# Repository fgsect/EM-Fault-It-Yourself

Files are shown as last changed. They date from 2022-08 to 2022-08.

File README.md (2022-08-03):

# EM-Fault It Yourself
This repository contains supplementary hardware design files and software to our paper 
[*EM-Fault It Yourself: Building a Replicable EMFI Setup for Desktop and Server Hardware*](). 
You can view it as a starting point to build your own customizable and open-source electromagnetic fault injection 
setup.

- `emfi_station/` contains the main controller software
- `marlin/` contains [Marlin](https://marlinfw.org/) configuration files
- `hardware/` contains hardware design files for 3D-printable parts

Detailed information can be found in the `README.md` files of the subdirectories.

## Software
The main controller software is a Python package called `emfi_station`. It provides a web interface to control the XYZ
stage, watch camera and sensor data and orchestrate complete electromagnetic fault injection attacks. To install the 
package clone this repository and run `pip`:

```shell
git clone 
pip install .
```

You can run *EMFI Station* using the command line:

```shell
usage: emfi-station [-h] [-i HOST] [-p PORT] [-s] [-a ATTACK_DIR] [-l LOG_DIR] [--marlin MARLIN] [--cal_cam CAL_CAM] [--pos_cam POS_CAM] [-v]

EMFI Station - Orchestrate electromagnetic fault injection attacks

options:
  -h, --help            show this help message and exit
  -i HOST, --host HOST  hostname or ip address
  -p PORT, --port PORT  http port (websocket port = http port + 1)
  -s, --simulate        simulate connection to Marlin
  -a ATTACK_DIR, --attack_dir ATTACK_DIR
                        attack scripts directory
  -l LOG_DIR, --log_dir LOG_DIR
                        log files directory
  --marlin MARLIN       (vendor_id, product_id) of Marlin board
  --cal_cam CAL_CAM     (vendor_id, product_id) of calibration camera
  --pos_cam POS_CAM     (vendor_id, product_id) of positioning camera
  -v, --verbosity       enable info log level
```

### Attack Scripts
The *EMFI Station* has an interface in the form of an `Attack` base class (`attack.py`) to allow easy integration of 
task/attack scripts. Your own task/attack class should inherit from the base class and implement the required 
methods. Each class should have its own file and a unique name (name() method). You can specify a folder containing 
attack scripts in the command line parameters.

## Troubleshooting
If you experience a `select timeout` while running *EMFI Station* under Raspbian, please try to adjust the quirks 
parameter of the `uvcvideo` kernel module:

```shell
rmmod uvcvideo
modprobe uvcvideo quirks=0x80
```

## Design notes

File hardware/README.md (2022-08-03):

# Hardware
The *EMFI Station* hardware is built out of commercially available as well as 3D-printable parts. Aluminum construction
profiles are used as a base frame for the other components:

<p align="center">
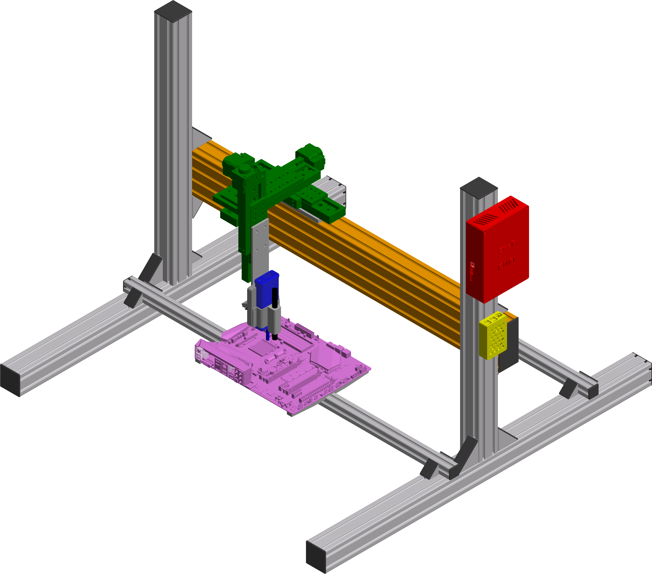
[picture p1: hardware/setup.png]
    
</p>

The following parts are commercially available:

- 1x [ChipShouter](https://www.newae.com/products/NAE-CW520)
- 3x [Standa 8MT175-100](https://www.standa.lt/products/catalog/motorised_positioners?item=60&prod=motorized_linear_stages)
- 3x [TMC2209 Stepper Driver](https://biqu.equipment/collections/driver-board/products/bigtreetech-tmc2209-stepper-motor-driver-for-3d-printer-board-vs-tmc2208)
- 1x [Bigtreetech SKR Pro v1.2](https://biqu.equipment/collections/control-board/products/bigtreetech-skr-pro-v1-1-32-bit-control-board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)
- 1x [Raspberry Pi 3B+](https://www.raspberrypi.com/products/raspberry-pi-3-model-b-plus/)
- 1x [Adafruit MLX90640 Thermal Camera](https://www.adafruit.com/product/4469)
- 1x [USB Microscope B007](https://www.supereyes-store.com/collections/microscopes/products/b007-300x-handheld-usb-digital-microscope-loupe-otoscope-magnifier-with-led-metal-stand)
- 1x [USB Microscope](https://www.amazon.de/TOOLCRAFT-Mikroskop-Pixel-Digitale-Vergr%C3%B6%C3%9Ferung/dp/B07L8M5BDJ)
- 1x [Power Supply](http://www.leicke.eu/de/products/NT03244)
- 1x [Angle Bracket](https://www.edmundoptics.de/p/metric-type-small-size-right-angle-bracket/12228/)
- 1x Aluminum Adapter Plates

All parts are mounted on an aluminum frame consisting of aluminum construction profiles. Please select these based on 
your needs. We used the following parts to achieve a working area large enough to target desktop and server hardware:

- 1x [12x6x100cm Profile](https://www.item24.com/en-de/profile-6-120x60-light-natural-41910/)
- 2x [6x6x100cm Profile](https://www.item24.com/en-de/profile-6-60x60-light-natural-41909/)
- 2x [3x3x100cm Profile](https://www.item24.com/en-de/profile-6-30x30-light-natural-41906/)
- 2x [6x6x70cm Profile](https://www.item24.com/en-de/profile-6-60x60-light-natural-41909/)
- 8x [6x6cm Angle](https://www.item24.com/en-de/angle-bracket-set-6-60x60-41968/)
- 8x [3x3cm Angle](https://www.item24.com/en-de/angle-bracket-set-6-30x30-41967/)
- Some [T-slot nuts](https://www.item24.com/en-de/t-slot-nut-f-6-st-m4-bright-zinc-plated-61323/)
- Some screws

Next to the commercially available parts, we 3D-printed mounts, cases and adapters. To allow an easy assembly, 
[threaded inserts](https://www.ruthex.de/collections/gewindeeinsatze) were used whenever threads were necessary in a 
3D-printed part. This folder contains all design (Autodesk Inventor (\*.ipt)) and print files (*.stl, *.stp):

- `skr_pro_case/` - Bigtreetech SKR Pro Case
- `ir_camera_mount/` - Thermal Camera Mount
- `chipshouter_mount/` - ChipShouter and Microscope Mount
- `atx_mount/` - ATX Mainboard Mount

Two aluminum adapter plates were specially produced based on our design. You can find the adapter plate design files 
in `adapter_plates/`.

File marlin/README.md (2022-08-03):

# Marlin Configuration
The XYZ stages are controlled by a 
[Bigtreetech SKR Pro v1.2](https://biqu.equipment/collections/control-board/products/bigtreetech-skr-pro-v1-1-32-bit-control-board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)
3D-printer mainboard running [Marlin](). It is equipped with 
[TMC2209 stepper drivers](https://biqu.equipment/collections/driver-board/products/bigtreetech-tmc2209-stepper-motor-driver-for-3d-printer-board-vs-tmc2208)
for quiet and smooth movements.

You can use the provided configuration files to build a custom firmware version based on **Marlin 2.0.9.2**. We 
configured Marlin to work best with the stepper drivers and *EMFI Station*. More information on how to build and 
configure the firmware can be found in the [Marlin installation guide](https://marlinfw.org/docs/basics/install.html).

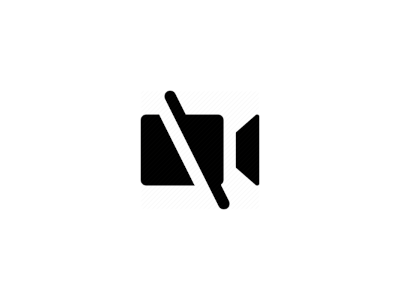
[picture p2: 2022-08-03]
emfi_station/web/cam_unavailable.png

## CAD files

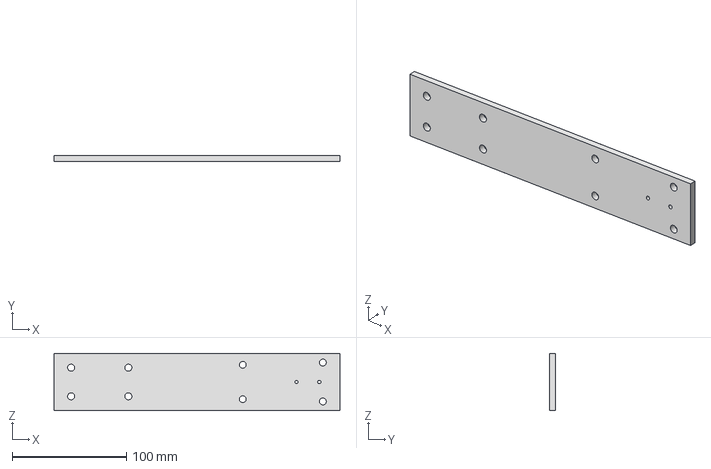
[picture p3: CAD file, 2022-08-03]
hardware/adapter_plates/adapter_chipshouter.stp
250.0 x 5.00 x 50.0 mm

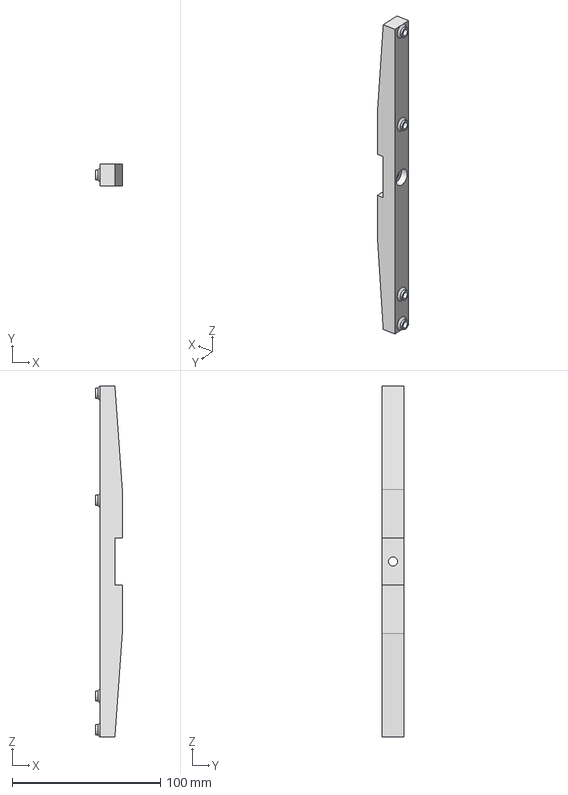
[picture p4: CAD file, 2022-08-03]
hardware/atx_mount/atx_mount.stp
18.0 x 15.0 x 237.0 mm

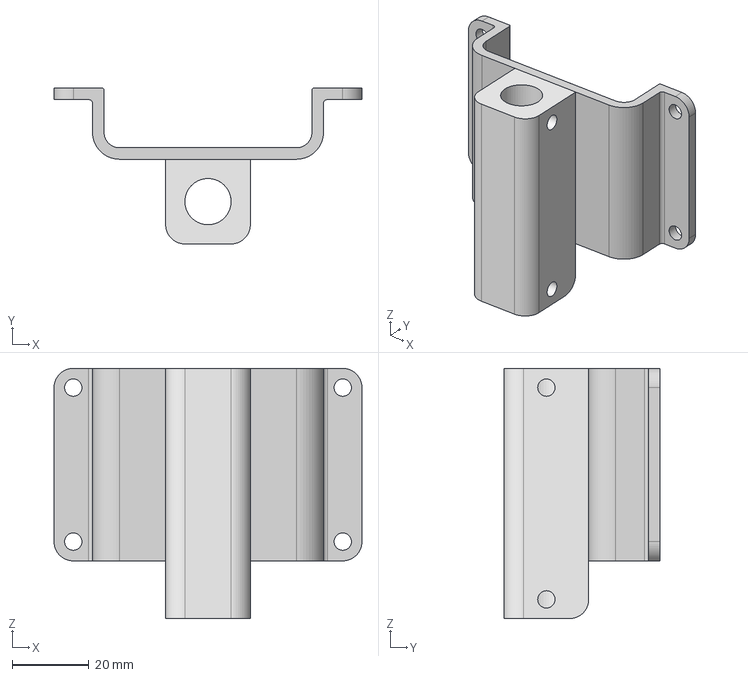
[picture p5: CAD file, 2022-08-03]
hardware/chipshouter_mount/chipshouter_mount.stp
80.0 x 40.5 x 65.0 mm
microscope_mount
chipshouter_mount_bracket

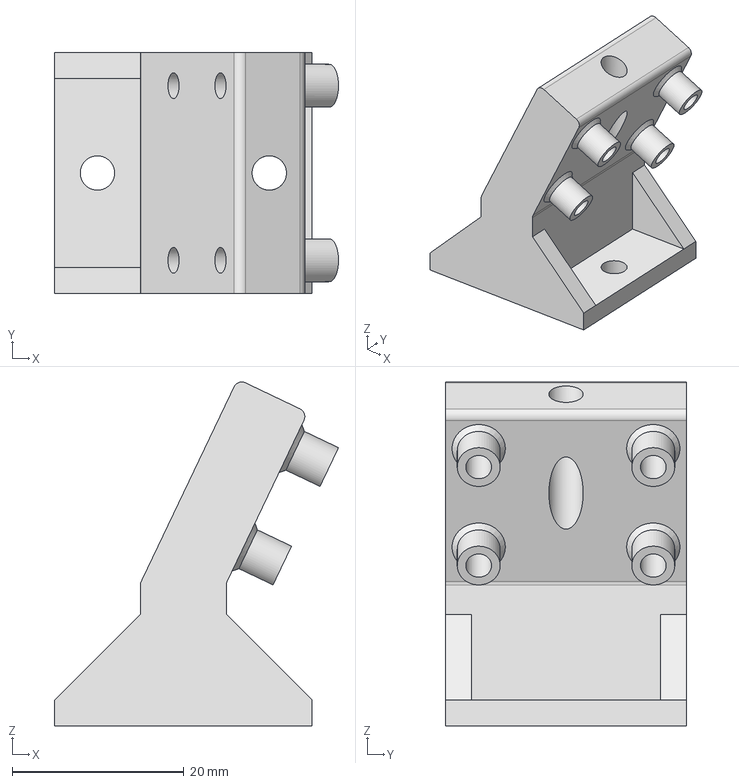
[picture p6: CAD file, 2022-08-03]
hardware/ir_camera_mount/ir_camera_mount.stp
33.1 x 28.0 x 40.0 mm

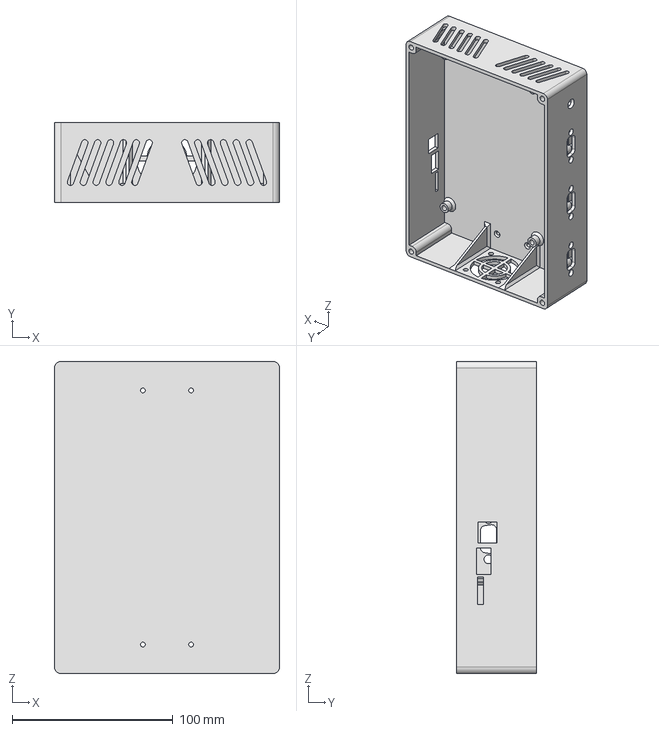
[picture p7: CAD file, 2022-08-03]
hardware/skr_pro_case/skr_case.stp
140.0 x 50.0 x 194.0 mm

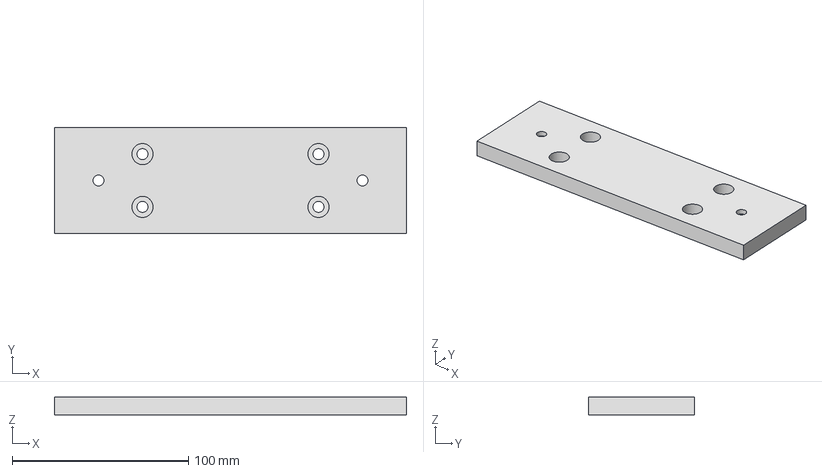
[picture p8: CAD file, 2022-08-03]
hardware/adapter_plates/adapter_stage.stp
200.0 x 60.0 x 10.0 mm

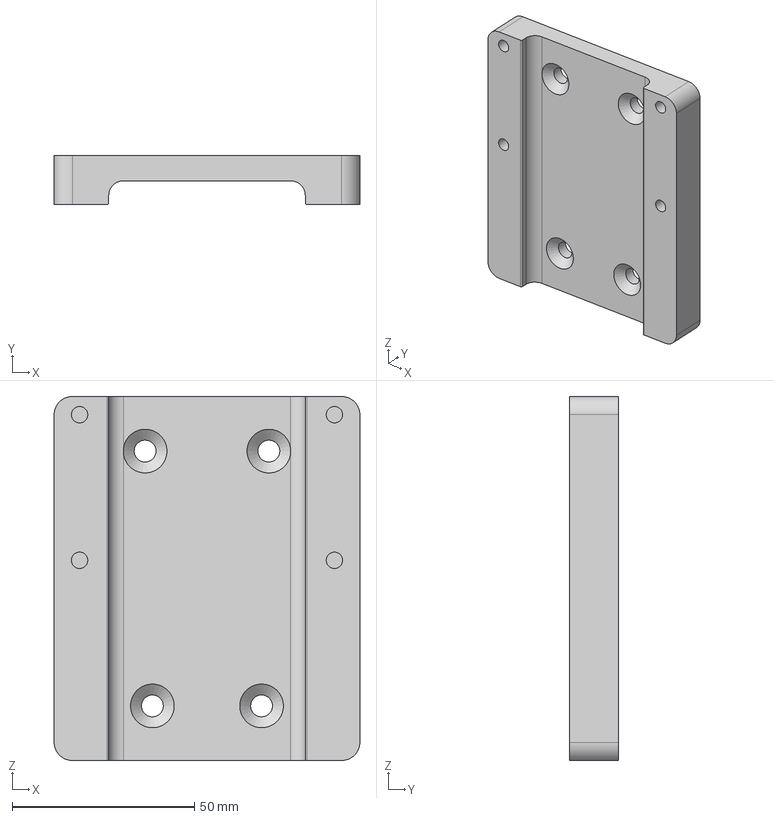
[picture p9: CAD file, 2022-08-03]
hardware/chipshouter_mount/chipshouter_mount_bottom.stp
84.0 x 13.5 x 100.0 mm

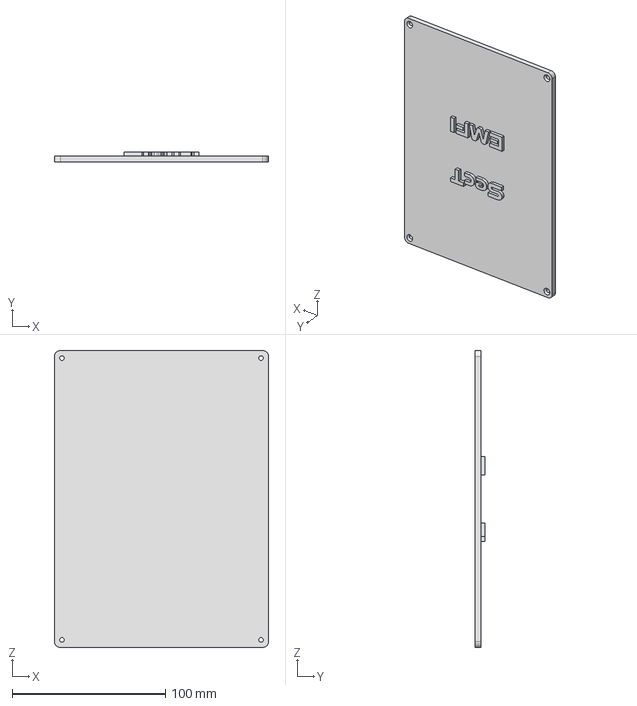
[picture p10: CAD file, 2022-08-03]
hardware/skr_pro_case/skr_case_top.stp
140.0 x 6.50 x 194.0 mm

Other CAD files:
hardware/adapter_plates/adapter_chipshouter.ipt
hardware/adapter_plates/adapter_chipshouter.stl
hardware/adapter_plates/adapter_stage.ipt
hardware/adapter_plates/adapter_stage.stl
hardware/atx_mount/atx_mount.ipt
hardware/atx_mount/atx_mount.stl
hardware/chipshouter_mount/chipshouter_mount.stl
hardware/chipshouter_mount/chipshouter_mount_assembly.iam
hardware/chipshouter_mount/chipshouter_mount_bottom.ipt
hardware/chipshouter_mount/chipshouter_mount_bottom.stl
hardware/chipshouter_mount/chipshouter_mount_bracket.ipt
hardware/chipshouter_mount/microscope_mount.ipt
hardware/ir_camera_mount/ir_camera_mount.ipt
hardware/ir_camera_mount/ir_camera_mount.stl
hardware/skr_pro_case/skr_case.ipt
hardware/skr_pro_case/skr_case.stl
hardware/skr_pro_case/skr_case_top.ipt
hardware/skr_pro_case/skr_case_top.stl

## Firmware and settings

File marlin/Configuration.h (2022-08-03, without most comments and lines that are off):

#pragma once
#define CONFIGURATION_H_VERSION 02000902
#define STRING_CONFIG_H_AUTHOR "(niclasku)" // Who made the changes.
#define SHOW_BOOTSCREEN
#define SERIAL_PORT -1
#define BAUDRATE 250000
  #define MOTHERBOARD BOARD_BTT_SKR_PRO_V1_2
#define CUSTOM_MACHINE_NAME "XYZ Controller"
#define MACHINE_UUID "5f4cca6f-12ec-4dfb-b79a-414b8f90fdfe"
#define LINEAR_AXES 3
#if LINEAR_AXES >= 4
  #define AXIS4_NAME 'A' // :['A', 'B', 'C', 'U', 'V', 'W']
#endif
#if LINEAR_AXES >= 5
  #define AXIS5_NAME 'B' // :['A', 'B', 'C', 'U', 'V', 'W']
#endif
#if LINEAR_AXES >= 6
  #define AXIS6_NAME 'C' // :['A', 'B', 'C', 'U', 'V', 'W']
#endif
#define EXTRUDERS 0
#define DEFAULT_NOMINAL_FILAMENT_DIA 1.75
#define TEMP_SENSOR_0 0
#define TEMP_SENSOR_1 0
#define TEMP_SENSOR_2 0
#define TEMP_SENSOR_3 0
#define TEMP_SENSOR_4 0
#define TEMP_SENSOR_5 0
#define TEMP_SENSOR_6 0
#define TEMP_SENSOR_7 0
#define TEMP_SENSOR_BED 0
#define TEMP_SENSOR_PROBE 0
#define TEMP_SENSOR_CHAMBER 0
#define TEMP_SENSOR_COOLER 0
#define TEMP_SENSOR_BOARD 0
#define TEMP_SENSOR_REDUNDANT 0
#define DUMMY_THERMISTOR_998_VALUE  25
#define DUMMY_THERMISTOR_999_VALUE 100
#define TEMP_RESIDENCY_TIME         10  // (seconds) Time to wait for hotend to "settle" in M109
#define TEMP_WINDOW                  1  // (°C) Temperature proximity for the "temperature reached" timer
#define TEMP_HYSTERESIS              3  // (°C) Temperature proximity considered "close enough" to the target
#define TEMP_BED_RESIDENCY_TIME     10  // (seconds) Time to wait for bed to "settle" in M190
#define TEMP_BED_WINDOW              1  // (°C) Temperature proximity for the "temperature reached" timer
#define TEMP_BED_HYSTERESIS          3  // (°C) Temperature proximity considered "close enough" to the target
#define TEMP_CHAMBER_RESIDENCY_TIME 10  // (seconds) Time to wait for chamber to "settle" in M191
#define TEMP_CHAMBER_WINDOW          1  // (°C) Temperature proximity for the "temperature reached" timer
#define TEMP_CHAMBER_HYSTERESIS      3  // (°C) Temperature proximity considered "close enough" to the target
#if TEMP_SENSOR_REDUNDANT
  #define TEMP_SENSOR_REDUNDANT_SOURCE    E1  // The sensor that will provide the redundant reading.
  #define TEMP_SENSOR_REDUNDANT_TARGET    E0  // The sensor that we are providing a redundant reading for.
  #define TEMP_SENSOR_REDUNDANT_MAX_DIFF  10  // (°C) Temperature difference that will trigger a print abort.
#endif
#define HEATER_0_MINTEMP   5
#define HEATER_1_MINTEMP   5
#define HEATER_2_MINTEMP   5
#define HEATER_3_MINTEMP   5
#define HEATER_4_MINTEMP   5
#define HEATER_5_MINTEMP   5
#define HEATER_6_MINTEMP   5
#define HEATER_7_MINTEMP   5
#define BED_MINTEMP        5
#define CHAMBER_MINTEMP    5
#define HEATER_0_MAXTEMP 275
#define HEATER_1_MAXTEMP 275
#define HEATER_2_MAXTEMP 275
#define HEATER_3_MAXTEMP 275
#define HEATER_4_MAXTEMP 275
#define HEATER_5_MAXTEMP 275
#define HEATER_6_MAXTEMP 275
#define HEATER_7_MAXTEMP 275
#define BED_MAXTEMP      150
#define CHAMBER_MAXTEMP  60
#define HOTEND_OVERSHOOT 15   // (°C) Forbid temperatures over MAXTEMP - OVERSHOOT
#define BED_OVERSHOOT    10   // (°C) Forbid temperatures over MAXTEMP - OVERSHOOT
#define COOLER_OVERSHOOT  2   // (°C) Forbid temperatures closer than OVERSHOOT
#define PIDTEMP
#define BANG_MAX 255     // Limits current to nozzle while in bang-bang mode; 255=full current
#define PID_MAX BANG_MAX // Limits current to nozzle while PID is active (see PID_FUNCTIONAL_RANGE below); 255=full current
#define PID_K1 0.95      // Smoothing factor within any PID loop
    #define DEFAULT_Kp  22.20
    #define DEFAULT_Ki   1.08
    #define DEFAULT_Kd 114.00
#define MAX_BED_POWER 255 // limits duty cycle to bed; 255=full current
#define MAX_CHAMBER_POWER 255 // limits duty cycle to chamber heater; 255=full current
  #define PID_FUNCTIONAL_RANGE 10 // If the temperature difference between the target temperature and the actual temperature
#define PREVENT_COLD_EXTRUSION
#define EXTRUDE_MINTEMP 170
#define PREVENT_LENGTHY_EXTRUDE
#define EXTRUDE_MAXLENGTH 200
#define THERMAL_PROTECTION_HOTENDS // Enable thermal protection for all extruders
#define THERMAL_PROTECTION_BED     // Enable thermal protection for the heated bed
#define THERMAL_PROTECTION_CHAMBER // Enable thermal protection for the heated chamber
#define THERMAL_PROTECTION_COOLER  // Enable thermal protection for the laser cooling
#define USE_XMIN_PLUG
#define USE_YMIN_PLUG
#define USE_ZMIN_PLUG
#define USE_XMAX_PLUG
#define USE_YMAX_PLUG
#define USE_ZMAX_PLUG
#define ENDSTOPPULLUPS
#define X_MIN_ENDSTOP_INVERTING true // Set to true to invert the logic of the endstop.
#define Y_MIN_ENDSTOP_INVERTING true // Set to true to invert the logic of the endstop.
#define Z_MIN_ENDSTOP_INVERTING true // Set to true to invert the logic of the endstop.
#define I_MIN_ENDSTOP_INVERTING false // Set to true to invert the logic of the endstop.
#define J_MIN_ENDSTOP_INVERTING false // Set to true to invert the logic of the endstop.
#define K_MIN_ENDSTOP_INVERTING false // Set to true to invert the logic of the endstop.
#define X_MAX_ENDSTOP_INVERTING true // Set to true to invert the logic of the endstop.
#define Y_MAX_ENDSTOP_INVERTING true // Set to true to invert the logic of the endstop.
#define Z_MAX_ENDSTOP_INVERTING true // Set to true to invert the logic of the endstop.
#define I_MAX_ENDSTOP_INVERTING false // Set to true to invert the logic of the endstop.
#define J_MAX_ENDSTOP_INVERTING false // Set to true to invert the logic of the endstop.
#define K_MAX_ENDSTOP_INVERTING false // Set to true to invert the logic of the endstop.
#define Z_MIN_PROBE_ENDSTOP_INVERTING false // Set to true to invert the logic of the probe.
#define X_DRIVER_TYPE  TMC2209
#define Y_DRIVER_TYPE  TMC2209
#define Z_DRIVER_TYPE  TMC2209
#define DETECT_BROKEN_ENDSTOP
#define DEFAULT_AXIS_STEPS_PER_UNIT   { 6400, 6400, 6400 }
#define DEFAULT_MAX_FEEDRATE          { 5, 5, 5 }
#define DEFAULT_MAX_ACCELERATION      { 1, 1, 1 }
#define DEFAULT_ACCELERATION          1    // X, Y, Z and E acceleration for printing moves
#define DEFAULT_RETRACT_ACCELERATION  1    // E acceleration for retracts
#define DEFAULT_TRAVEL_ACCELERATION   1    // X, Y, Z acceleration for travel (non printing) moves
#define DEFAULT_EJERK    5.0  // May be used by Linear Advance
  #define JUNCTION_DEVIATION_MM 0.013 // (mm) Distance from real junction edge
  #define JD_HANDLE_SMALL_SEGMENTS    // Use curvature estimation instead of just the junction angle
#define NOZZLE_TO_PROBE_OFFSET { 10, 10, 0 }
#define PROBING_MARGIN 10
#define XY_PROBE_FEEDRATE (133*60)
#define Z_PROBE_FEEDRATE_FAST (4*60)
#define Z_PROBE_FEEDRATE_SLOW (Z_PROBE_FEEDRATE_FAST / 2)
#define Z_CLEARANCE_DEPLOY_PROBE   10 // Z Clearance for Deploy/Stow
#define Z_CLEARANCE_BETWEEN_PROBES  5 // Z Clearance between probe points
#define Z_CLEARANCE_MULTI_PROBE     5 // Z Clearance between multiple probes
#define Z_PROBE_LOW_POINT          -2 // Farthest distance below the trigger-point to go before stopping
#define Z_PROBE_OFFSET_RANGE_MIN -20
#define Z_PROBE_OFFSET_RANGE_MAX 20
#define X_ENABLE_ON 0
#define Y_ENABLE_ON 0
#define Z_ENABLE_ON 0
#define E_ENABLE_ON 0 // For all extruders
#define DISABLE_X false
#define DISABLE_Y false
#define DISABLE_Z false
#define DISABLE_E false             // Disable the extruder when not stepping
#define DISABLE_INACTIVE_EXTRUDER   // Keep only the active extruder enabled
#define INVERT_X_DIR false
#define INVERT_Y_DIR false
#define INVERT_Z_DIR false
#define INVERT_E0_DIR false
#define INVERT_E1_DIR false
#define INVERT_E2_DIR false
#define INVERT_E3_DIR false
#define INVERT_E4_DIR false
#define INVERT_E5_DIR false
#define INVERT_E6_DIR false
#define INVERT_E7_DIR false
#define Z_HOMING_HEIGHT  0      // (mm) Minimal Z height before homing (G28) for Z clearance above the bed, clamps, ...
#define X_HOME_DIR -1
#define Y_HOME_DIR -1
#define Z_HOME_DIR -1
#define X_BED_SIZE 100
#define Y_BED_SIZE 100
#define X_MIN_POS 0
#define Y_MIN_POS 0
#define Z_MIN_POS 0
#define X_MAX_POS X_BED_SIZE
#define Y_MAX_POS Y_BED_SIZE
#define Z_MAX_POS 100
#define MIN_SOFTWARE_ENDSTOPS
  #define MIN_SOFTWARE_ENDSTOP_X
  #define MIN_SOFTWARE_ENDSTOP_Y
  #define MIN_SOFTWARE_ENDSTOP_Z
  #define MIN_SOFTWARE_ENDSTOP_I
  #define MIN_SOFTWARE_ENDSTOP_J
  #define MIN_SOFTWARE_ENDSTOP_K
#define MAX_SOFTWARE_ENDSTOPS
  #define MAX_SOFTWARE_ENDSTOP_X
  #define MAX_SOFTWARE_ENDSTOP_Y
  #define MAX_SOFTWARE_ENDSTOP_Z
  #define MAX_SOFTWARE_ENDSTOP_I
  #define MAX_SOFTWARE_ENDSTOP_J
  #define MAX_SOFTWARE_ENDSTOP_K
#define DEBUG_LEVELING_FEATURE
#define HOMING_FEEDRATE_MM_M { (2*60), (2*60), (2*60) }
#define VALIDATE_HOMING_ENDSTOPS
#define EEPROM_SETTINGS     // Persistent storage with M500 and M501
#define EEPROM_CHITCHAT       // Give feedback on EEPROM commands. Disable to save PROGMEM.
#define EEPROM_BOOT_SILENT    // Keep M503 quiet and only give errors during first load
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

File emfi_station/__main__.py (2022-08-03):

# EMFI Station - Orchestrate electromagnetic fault injection attacks
# Copyright (C) 2022 Niclas Kühnapfel
#
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
import sys
import logging
import argparse

from .config import Config
from .emfi_station import EMFIStation


def main():
    config = Config()
    parser = argparse.ArgumentParser(description='EMFI Station - Orchestrate electromagnetic fault injection attacks')
    parser.add_argument('-i', '--host', type=str, help='hostname or ip address')
    parser.add_argument('-p', '--port', type=int, help='http port (websocket port = http port + 1)')
    parser.add_argument('-s', '--simulate', action='store_true', help='simulate connection to Marlin')
    parser.add_argument('-a', '--attack_dir', type=str, help='attack scripts directory')
    parser.add_argument('-l', '--log_dir', type=str, help='log files directory')
    parser.add_argument('--marlin', type=tuple[str, str], help='(vendor_id, product_id) of Marlin board')
    parser.add_argument('--cal_cam', type=tuple[str, str], help='(vendor_id, product_id) of calibration camera')
    parser.add_argument('--pos_cam', type=tuple[str, str], help='(vendor_id, product_id) of positioning camera')
    parser.add_argument('-v', '--verbosity', action='store_true', help='enable info log level')
    args = parser.parse_args()

    if args.host is not None:
        config.host = args.host
    if args.port is not None:
        config.http_port = args.port
    if args.simulate is not True:
        config.simulate = args.simulate
    if args.attack_dir is not None:
        config.attack_dir = args.attack_dir
    if args.log_dir is not None:
        config.log_dir = args.log_dir
    if args.marlin is not None:
        config.marlin = args.marlin
    if args.cal_cam is not None:
        config.calibration_cam = args.cal_cam
    if args.pos_cam is not None:
        config.positioning_cam = args.pos_cam
    if args.verbosity is True:
        level = logging.INFO
    else:
        level = logging.ERROR

    logging.basicConfig(format='%(levelname)s:%(asctime)s:%(filename)s:%(message)s', stream=sys.stdout, level=level)
    EMFIStation(config)


if __name__ == '__main__':
    main()

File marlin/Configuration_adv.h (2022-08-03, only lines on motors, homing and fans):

#define E0_AUTO_FAN_PIN -1
#define E1_AUTO_FAN_PIN -1
#define E2_AUTO_FAN_PIN -1
#define E3_AUTO_FAN_PIN -1
#define E4_AUTO_FAN_PIN -1
#define E5_AUTO_FAN_PIN -1
#define E6_AUTO_FAN_PIN -1
#define E7_AUTO_FAN_PIN -1
#define CHAMBER_AUTO_FAN_PIN -1
#define COOLER_AUTO_FAN_PIN -1
#define COOLER_FAN_PIN -1
#define HOMING_BUMP_MM      { 2, 2, 2 }       // (mm) Backoff from endstops after first bump
#define HOMING_BUMP_DIVISOR { 4, 4, 4 }       // Re-Bump Speed Divisor (Divides the Homing Feedrate)
#define MICROSTEP_MODES { 16, 16, 16, 16, 16, 16 } // [1,2,4,8,16]
    #define X_CURRENT       800        // (mA) RMS current. Multiply by 1.414 for peak current.
    #define X_CURRENT_HOME  X_CURRENT  // (mA) RMS current for sensorless homing
    #define X_MICROSTEPS     16        // 0..256
    #define Y_CURRENT       800
    #define Y_CURRENT_HOME  Y_CURRENT
    #define Y_MICROSTEPS     16
    #define Z_CURRENT       800
    #define Z_CURRENT_HOME  Z_CURRENT
    #define Z_MICROSTEPS     16
    #define CURRENT_STEP_DOWN     50  // [mA]
    #define REPORT_CURRENT_CHANGE
  #define X_HYBRID_THRESHOLD     100  // [mm/s]
  #define X2_HYBRID_THRESHOLD    100
  #define Y_HYBRID_THRESHOLD     100
  #define Y2_HYBRID_THRESHOLD    100
  #define Z_HYBRID_THRESHOLD       3
  #define Z2_HYBRID_THRESHOLD      3
  #define Z3_HYBRID_THRESHOLD      3
  #define Z4_HYBRID_THRESHOLD      3
  #define I_HYBRID_THRESHOLD       3
  #define J_HYBRID_THRESHOLD       3
  #define K_HYBRID_THRESHOLD       3
  #define E0_HYBRID_THRESHOLD     30
  #define E1_HYBRID_THRESHOLD     30
  #define E2_HYBRID_THRESHOLD     30
  #define E3_HYBRID_THRESHOLD     30
  #define E4_HYBRID_THRESHOLD     30
  #define E5_HYBRID_THRESHOLD     30
  #define E6_HYBRID_THRESHOLD     30
  #define E7_HYBRID_THRESHOLD     30

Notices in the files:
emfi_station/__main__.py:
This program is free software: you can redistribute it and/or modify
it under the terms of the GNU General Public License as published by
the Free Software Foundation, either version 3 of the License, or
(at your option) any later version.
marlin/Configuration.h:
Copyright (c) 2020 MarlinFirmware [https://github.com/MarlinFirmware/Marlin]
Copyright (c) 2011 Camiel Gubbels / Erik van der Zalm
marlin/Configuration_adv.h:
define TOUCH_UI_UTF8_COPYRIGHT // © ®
